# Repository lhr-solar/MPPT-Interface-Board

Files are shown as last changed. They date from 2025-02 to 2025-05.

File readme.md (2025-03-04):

# MPPT-Interface-Board
Author: Ravi Shah  
This Power and CAN interface board for the TPPE SEC-B175-7A Maximum Power Point Tracker provides an interface allowing them to connect to fuse box power and CarCAN. Since CarCAN on Daybreak operates at 5V, a 12V (fusebox) to 9V isolated buck converter is used to meet the minimum 6V requirement of the MPPTs.
## BOM
Mouser Cart: https://www.mouser.com/ProjectManager/ProjectDetail.aspx?AccessID=ef21a76273  
IBOM: BOM/ibom.html (open and view in browser)
## Connectors
| # | Name | Type | Ideal Voltage |
| - | - | - | - |
| J1  | FIRST MPPT | Micro-Fit_3.0_43045-0612_2x03_P3.00mm_Vertical Female | +9V |
| J2  | LAST MPPT | Micro-Fit_3.0_43045-0612_2x03_P3.00mm_Vertical Female | +9V |
| J3  | CarCAN IN | Micro-Fit_3.0_43650-0415_1x04_P3.00mm_Vertical Female | +5V |
| J4  | CarCAN OUT | Micro-Fit_3.0_43650-0415_1x04_P3.00mm_Vertical Female | +5V |
| J5  | FUSEBOX | Micro-Fit_3.0_43650-0215_1x02_P3.00mm_Vertical Female | +12V |
## 3D Model

## PCB

## Schematic

## Application Note
The FIRST MPPT connector is for the first MPPT this board connects to. From there, up to 4 (unverified!) MPPTs can be daisy chained by connecting the output of the first MPPT to the input of the second and so on. The LAST MPPT connector is where the output of the last MPPT in the daisy chain should be connected.

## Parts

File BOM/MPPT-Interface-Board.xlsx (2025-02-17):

Reference | Value | Qty | P/N
C1,C2,C5 | 10u | 3 | TMK212BBJ106MGHT
C3 | 330p | 1 | 08053A331JAT2A
C4 | 470p | 1 | 08053C471JAT2A
D1 | SD12_SOD323 | 1 | SD12C.TCT
D2,D3,D4 | -- mixed values -- | 3 | APTD2012LCGCK
J1,J2 | -- mixed values -- | 2 | 430450612
J3,J4 | -- mixed values -- | 2 | 0436500415
J5 | FUSEBOX | 1 | 0436500215
Q1 | PMV35EPER | 1 | PMV35EPER
R1,R6 | 120 | 2 | CRCW0805120RFKEA
R2 | 100k | 1 | CRCW0805100KFKEAC
R3 | 5.1k | 1 | RCA08055K10FKEA
R4 | 1.69k | 1 | CRCW08051K69FKEA
R5 | 3.48k | 1 | CRCW08053K48FKEA
U1 | RI3-1209S | 1 | RI3-1209S
Z1 | BZT52-B12-QX | 1 | BZT52-B12-QX

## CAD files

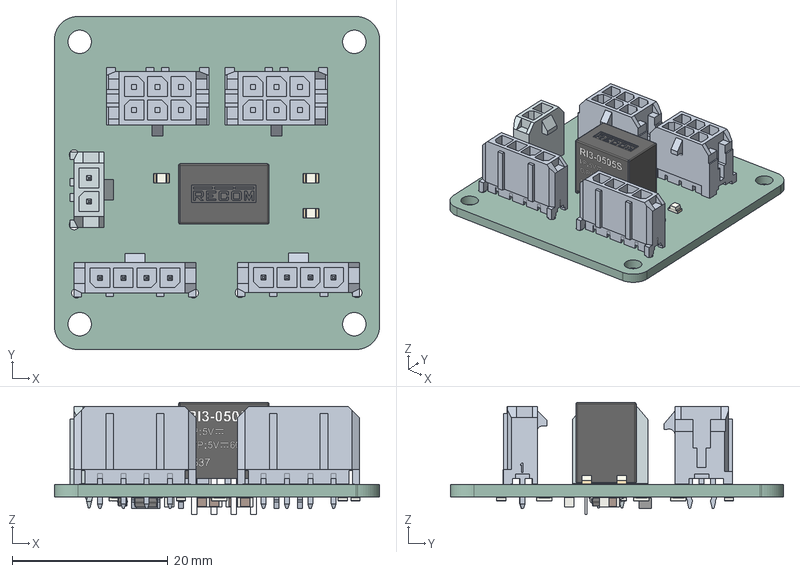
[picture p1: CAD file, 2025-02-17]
3D/MPPT-Interface-Board.step
41.8 x 42.8 x 14.4 mm
LED_0805_2012Metric x 3
436500215wbm000_01
RI3_case
RI3_pin4(+Vout)
RI3_pin1(-Vin
RI3_pin2(+Vin)
RI3_pin3(-Vout)
RI3_potting
R_0805_2012Metric x 6
ASSEMBLY
C_0805_2012Metric x 5
SOT_23
D_SOD_323
MPPT-Interface-Board_PCB

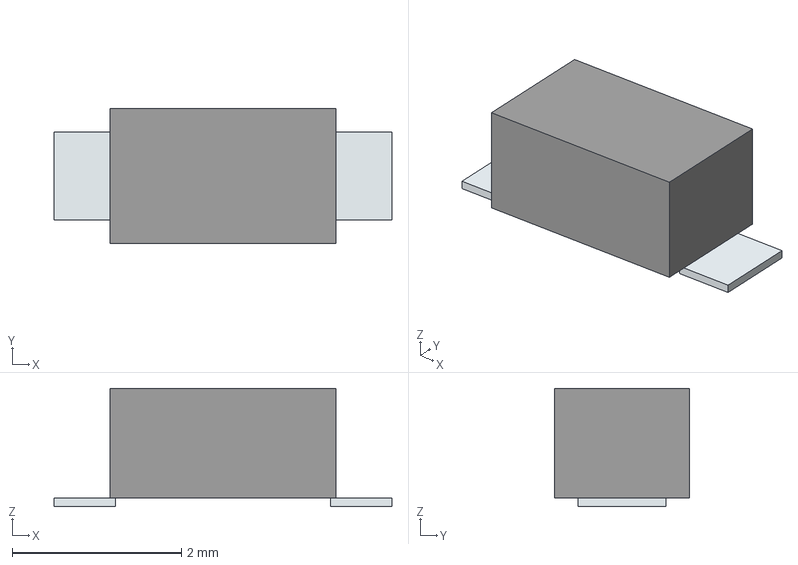
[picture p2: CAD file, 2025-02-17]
Custom-KiCadLibraries/BZT52-B12-QX/BZT52-B12-QX.stp
4.00 x 1.60 x 1.40 mm
Pins

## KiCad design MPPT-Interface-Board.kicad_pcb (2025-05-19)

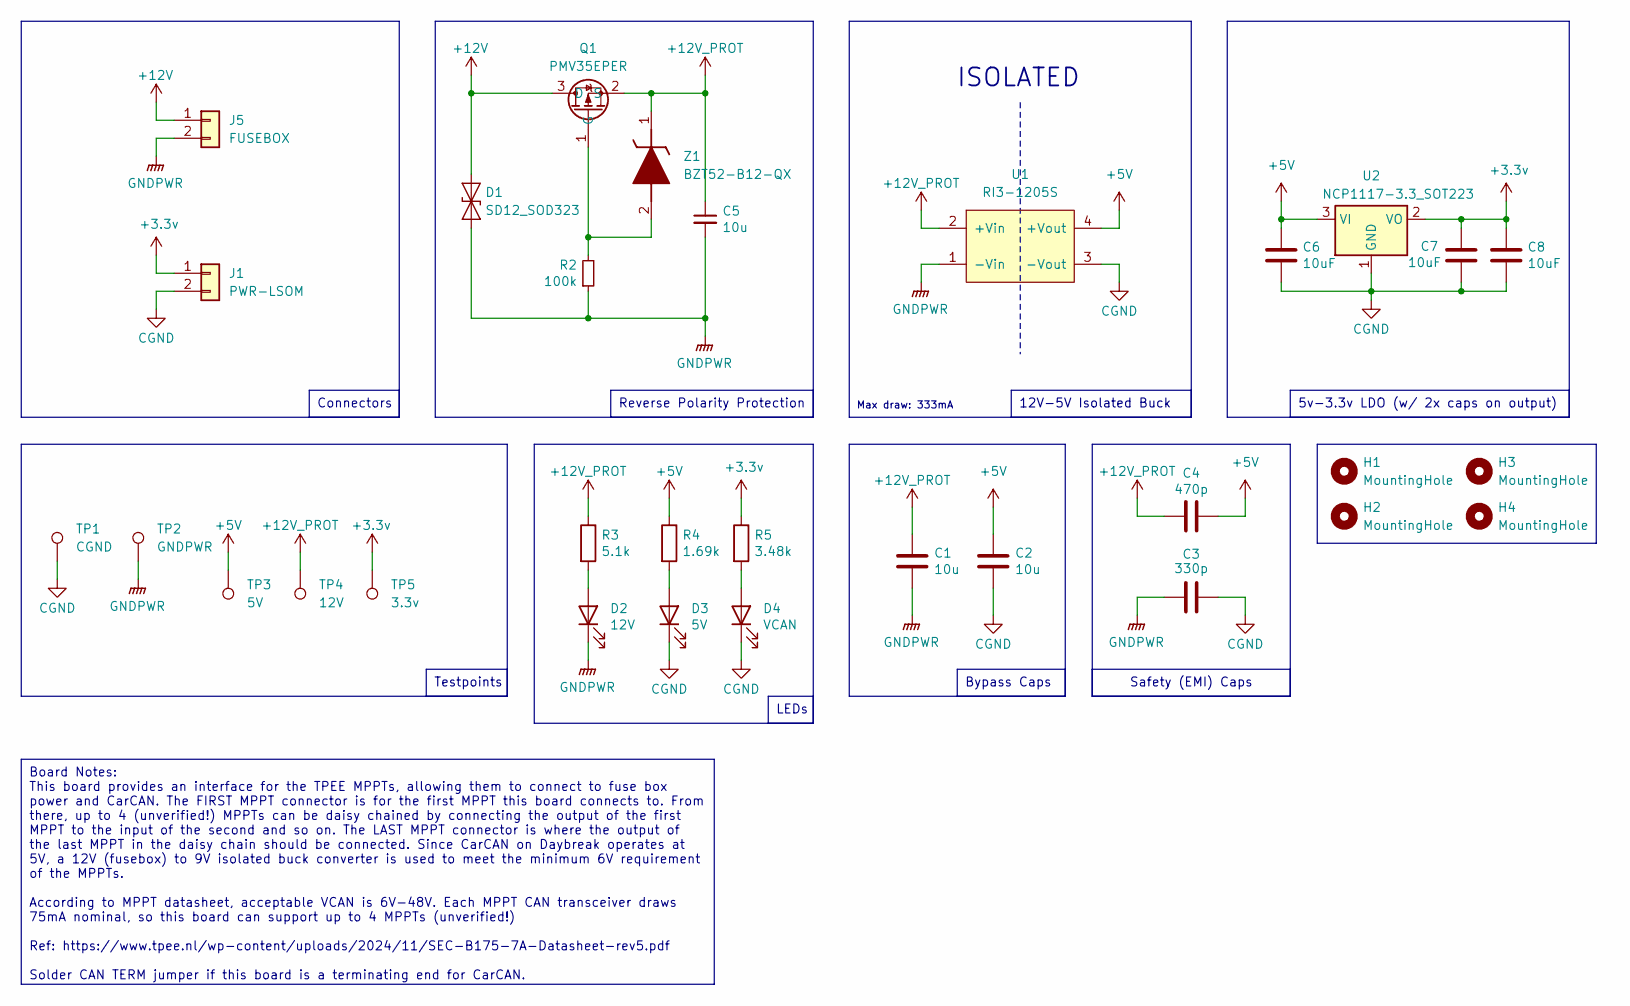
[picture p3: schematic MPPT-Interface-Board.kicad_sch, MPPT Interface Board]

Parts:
C1, C2: 10u; C_0805_2012Metric; Mouser Part Number 581-22201C106KAT2A
C3: 330p; C_0805_2012Metric
C4: 470p; C_0805_2012Metric
C5: 10u; C_0805_2012Metric
C6, C7, C8: 10uF; C_0805_2012Metric; Mouser Part Number 963-TMK212BBJ106MGHT
D1: SD12_SOD323; D_SOD-323
D2: 12V; LED_0805_2012Metric; Mouser Part Number 604-APTD2012LCGCK
D3: 5V; LED_0805_2012Metric; Mouser Part Number 604-APTD2012LCGCK
D4: VCAN; LED_0805_2012Metric; Mouser Part Number 604-APTD2012LCGCK
H1, H2, H3, H4: MountingHole; MountingHole_3mm
J1: PWR-LSOM; Molex_Micro-Fit_3.0_43650-0215_1x02_P3.00mm_Vertical
J5: FUSEBOX; Molex_Micro-Fit_3.0_43650-0215_1x02_P3.00mm_Vertical
Q1: PMV35EPER; SOT-23
R2: 100k; R_0805_2012Metric
R3: 5.1k; R_0805_2012Metric; Mouser Part Number 71-CRCW0805-22.1K-E3
R4: 1.69k; R_0805_2012Metric; Mouser Part Number 71-CRCW0805-22.1K-E3
R5: 3.48k; R_0805_2012Metric; Mouser Part Number 71-CRCW0805-22.1K-E3
TP1: CGND; TestPoint_Pad_1.0x1.0mm
TP2: GNDPWR; TestPoint_Pad_1.0x1.0mm
TP3: 5V; TestPoint_Pad_1.0x1.0mm
TP4: 12V; TestPoint_Pad_1.0x1.0mm
TP5: 3.3v; TestPoint_Pad_1.0x1.0mm
U1: RI3-1205S; RI3_DC_Converter; Mouser Part Number 919-RI3-1205S
U2: NCP1117-3.3_SOT223; SOT-223-3_TabPin2; Mouser Part Number 863-NCP1117ST33T3G
Z1: BZT52-B12-QX; BZT52B12QX; Mouser Part Number 771-BZT52-B12-QX

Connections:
+3.3v: C7.1, C8.1, J1.1, R5.1, TP5.1, U2.2 (VO)
+5V: C2.1, C4.2, C6.1, R4.1, TP3.1, U1.4 (+Vout), U2.3 (VI)
+12V: D1.2 (A2), J5.1, Q1.3 (D)
+12V_PROT: C1.1, C4.1, C5.1, Q1.2 (S), R3.1, TP4.1, U1.2 (+Vin), Z1.1 (K)
CGND: C2.2, C3.2, C6.2, C7.2, C8.2, D3.1 (K), D4.1 (K), J1.2, TP1.1, U1.3 (-Vout), U2.1 (GND)
GNDPWR: C1.2, C3.1, C5.2, D1.1 (A1), D2.1 (K), J5.2, R2.1, TP2.1, U1.1 (-Vin)
unnamed: D2.2 (A), R3.2
unnamed: D3.2 (A), R4.2
unnamed: D4.2 (A), R5.2
unnamed: Q1.1 (G), R2.2, Z1.2 (A)

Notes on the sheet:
Board Notes: This board provides an interface for the TPEE MPPTs, allowing them to connect to fuse box power and CarCAN. The FIRST MPPT connector is for the first MPPT this board connects to. From there, up to 4 (unverified!) MPPTs can be daisy chained by connecting the output of the first MPPT to 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
Connectors
Reverse Polarity Protection
Testpoints
LEDs
Safety (EMI) Caps
Bypass Caps
12V-5V Isolated Buck
5v-3.3v LDO (w/ 2x caps on output)
ISOLATED
Max draw: 333mA

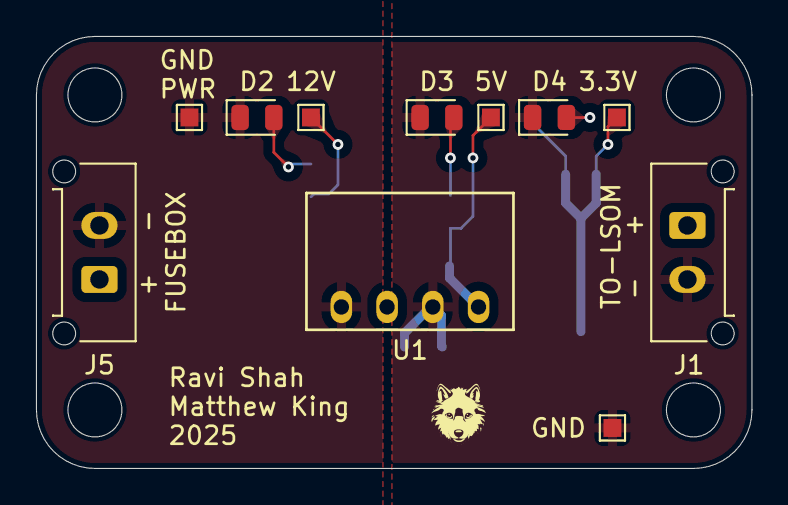
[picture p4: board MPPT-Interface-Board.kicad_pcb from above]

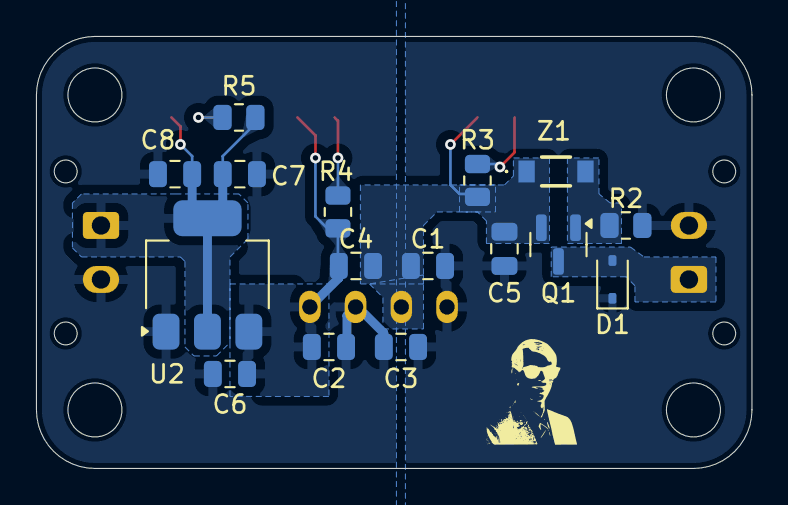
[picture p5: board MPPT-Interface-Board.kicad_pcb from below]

Board: 2 copper layers, 39.8 x 24.0 mm, 31 parts (16 on the bottom side), 10 nets.

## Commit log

2025-02-10 add kicad project
    [MPPT-Interface-Board.kicad_pcb, MPPT-Interface-Board.kicad_sch]
2025-02-10 update symbols/footprints from lib
    [MPPT-Interface-Board.kicad_pcb]
2025-02-15 initial sch
    [CAN.kicad_sch, MPPT-Interface-Board.kicad_pcb, MPPT-Interface-Board.kicad_sch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]
2025-02-15 add candapter conn
    [MPPT-Interface-Board.kicad_sch]
2025-02-15 add RPP
    [BZT52-B12-QX.stp, MPPT-Interface-Board.kicad_sch]
2025-02-15 fix loop?
    [MPPT-Interface-Board.kicad_sch]
2025-02-15 add indicator LEDs
    [MPPT-Interface-Board.kicad_pcb, MPPT-Interface-Board.kicad_sch]
2025-02-15 more fixes
    [MPPT-Interface-Board.kicad_sch]
2025-02-15 P/N for everything
    [MPPT-Interface-Board.kicad_sch]
2025-02-15 fix bypass cap
    [MPPT-Interface-Board.kicad_sch]
2025-02-16 uhm so why am i so stupid
    [MPPT-Interface-Board.kicad_sch]
2025-02-16 initial layout (unrouted)
    [MPPT-Interface-Board.kicad_pcb, MPPT-Interface-Board.kicad_sch]
2025-02-16 add silk labels
    [MPPT-Interface-Board.kicad_pcb]
2025-02-16 change carcan to 4 pin & add start termination
    [MPPT-Interface-Board.kicad_sch]
2025-02-17 redo layout/routing/silks
    [MPPT-Interface-Board.kicad_pcb, MPPT-Interface-Board.kicad_sch]
2025-02-17 lil smaller
    [MPPT-Interface-Board.kicad_pcb]
2025-02-17 3d & BOM
    [MPPT-Interface-Board.step, MPPT-Interface-Board.xlsx]
2025-02-17 cant read ig
    [MPPT-Interface-Board.kicad_pcb]
2025-02-17 make gndpwr larger
    [CAN.kicad_sch, MPPT-Interface-Board.kicad_pcb, Power.kicad_sch]
2025-02-17 lakshay make board black pls
    [MPPT-Interface-Board.kicad_pcb, MPPT-Interface-Board.kicad_sch]
2025-02-17 fix plane connection
    [MPPT-Interface-Board.kicad_pcb]
2025-02-17 board notes + readme stuff
    [MPPT-Interface-Board.kicad_sch]
2025-02-17 add pcb, sch, 3d to readme
2025-03-04 add connectors table to readme
2025-05-18 Changed up to interface data acq leader
    [MPPT-Interface-Board.kicad_pcb, MPPT-Interface-Board.kicad_sch]
2025-05-19 Smaller version - gerbers made
    [MPPT-Interface-Board-B_Cu.gbr, MPPT-Interface-Board-B_Mask.gbr, MPPT-Interface-Board-B_Paste.gbr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]
